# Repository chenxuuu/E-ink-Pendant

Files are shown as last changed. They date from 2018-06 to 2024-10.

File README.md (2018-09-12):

# E-ink Pendant

## 项目介绍
基于电子墨水屏与gprs的，科创纪念钥匙链挂饰，服务器为php驱动

## 项目文件结构
- 硬件设计
  - 硬件资料
  - 硬件工程文件
- 嵌入式软件
  - Air202工程脚本
  - Air202所用固件
- 服务器部分
  - 服务器整体框架
  - 公开的二次开发api以及demo sdk

## 需要实现的功能
- 驱动电子墨水屏幕，SPI控制，分辨率200*200
- 锂电池供电，可实时显示电压（剩余电量）
- 可充电
- 定时刷新电子墨水屏界面
- 界面显示内容可在网站端设置
- 所有设置可在网站端修改
- 提供屏幕显示内容模板
- 提供自定义显示内容模板设置（开放api）
- 提供外部链接的api接口
- 网站的账号注册以及绑定设备流程

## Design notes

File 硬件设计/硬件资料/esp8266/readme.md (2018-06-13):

# 淘宝链接

https://item.taobao.com/item.htm?id=538926731077

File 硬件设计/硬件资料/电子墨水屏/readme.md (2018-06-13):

# 淘宝链接

https://item.taobao.com/item.htm?id=45437569090

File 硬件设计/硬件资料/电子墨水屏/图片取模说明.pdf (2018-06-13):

# GDEH0154D27 图片制作及取模说明

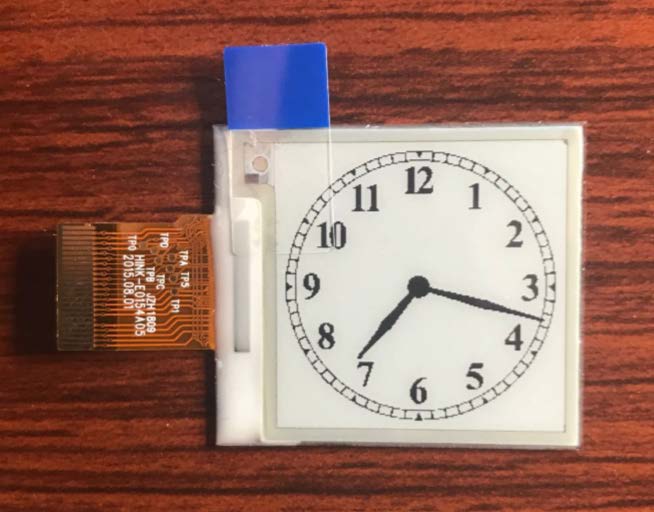
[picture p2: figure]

图一

### 以实现上图效果为例，对图片制作及取模加以简要说明。

一、 | 图片制作
| 因为该款屏不支持灰度，所以在制作图片的时候，需要做成 200*200 分辨率的

纯黑白图片，保存成.bmp 位图文件。

二、 取模

取模可以采用 image2lcd 软件，取模参数设置见图二：

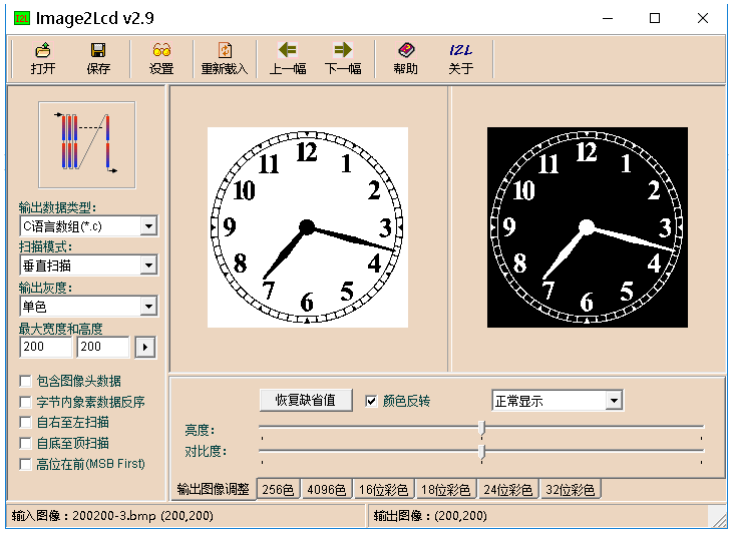
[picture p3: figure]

图二

1、 打开 image2lcd，调入需要取模的图片；

2、 输出数据类型：选择“C 语言数组（*.c）”；

3、 扫描方式：选择“垂直扫描”；

4、 输出灰度：选择“单色”；

5、 最大宽度和高度：选择“200”、“200”，选择后需要点击后面的箭头确认；

6、 左下方的 5 个选项都不要打钩；

7、 正显（白底黑字），则“颜色反转”打钩；负显（黑底白字）则不需要打钩。

8、 点击“保存”，把转换后的数组存到扩展名为“.C”文件；

9、 最后把文件“.C”中的数组替换掉程序中对应的数组。

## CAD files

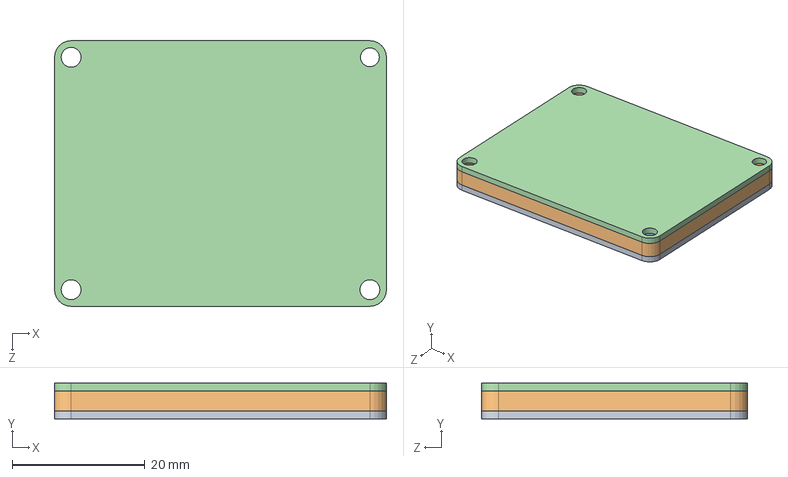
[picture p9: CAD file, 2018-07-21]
硬件设计/外壳图纸/装配体1.SLDASM
50.0 x 5.40 x 40.0 mm
下板
中板
电池
上板

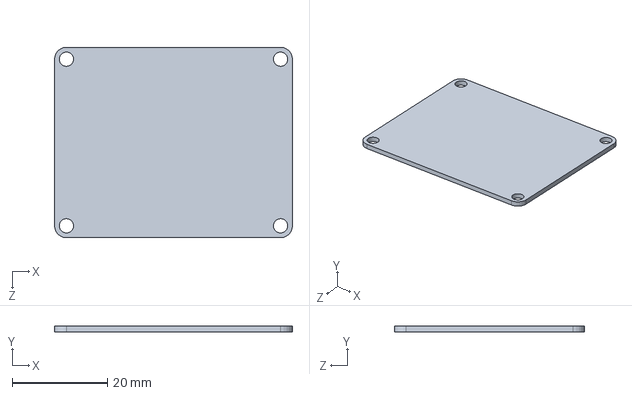
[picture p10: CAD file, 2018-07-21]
硬件设计/外壳图纸/下板.SLDPRT
50.0 x 1.20 x 40.0 mm

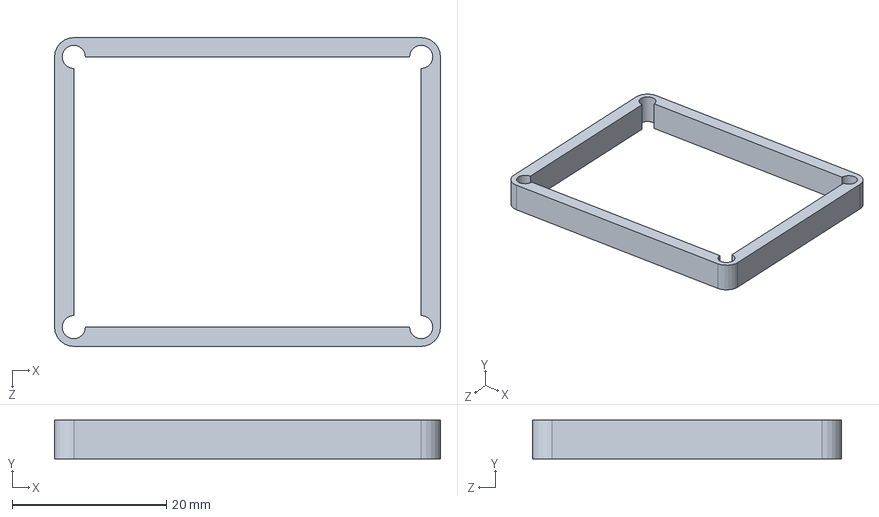
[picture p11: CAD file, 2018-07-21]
硬件设计/外壳图纸/中板.SLDPRT
50.0 x 5.00 x 40.0 mm

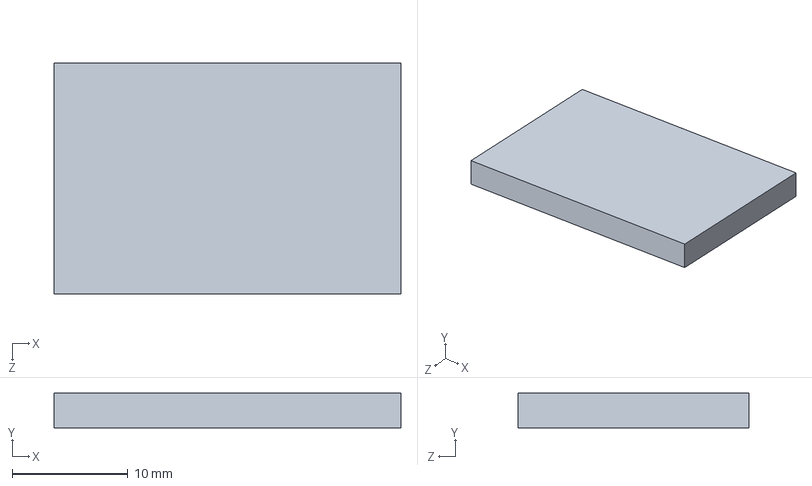
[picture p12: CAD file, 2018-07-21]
硬件设计/外壳图纸/电池.SLDPRT
30.0 x 3.00 x 20.0 mm

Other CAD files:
硬件设计/外壳图纸/上板.SLDPRT

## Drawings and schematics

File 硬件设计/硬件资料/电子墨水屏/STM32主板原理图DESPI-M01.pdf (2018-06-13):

## Current test1

## ASM1117-3.3

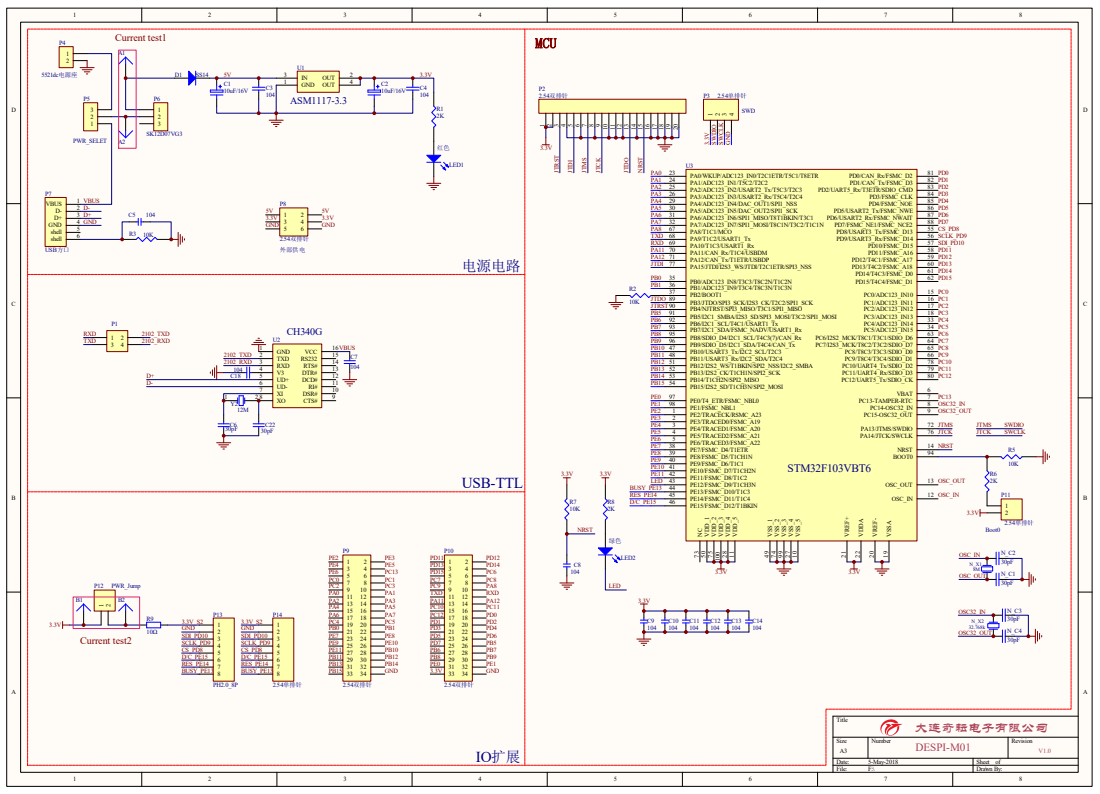
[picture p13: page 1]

SWD 3.3V SWDIO SWCLK GND

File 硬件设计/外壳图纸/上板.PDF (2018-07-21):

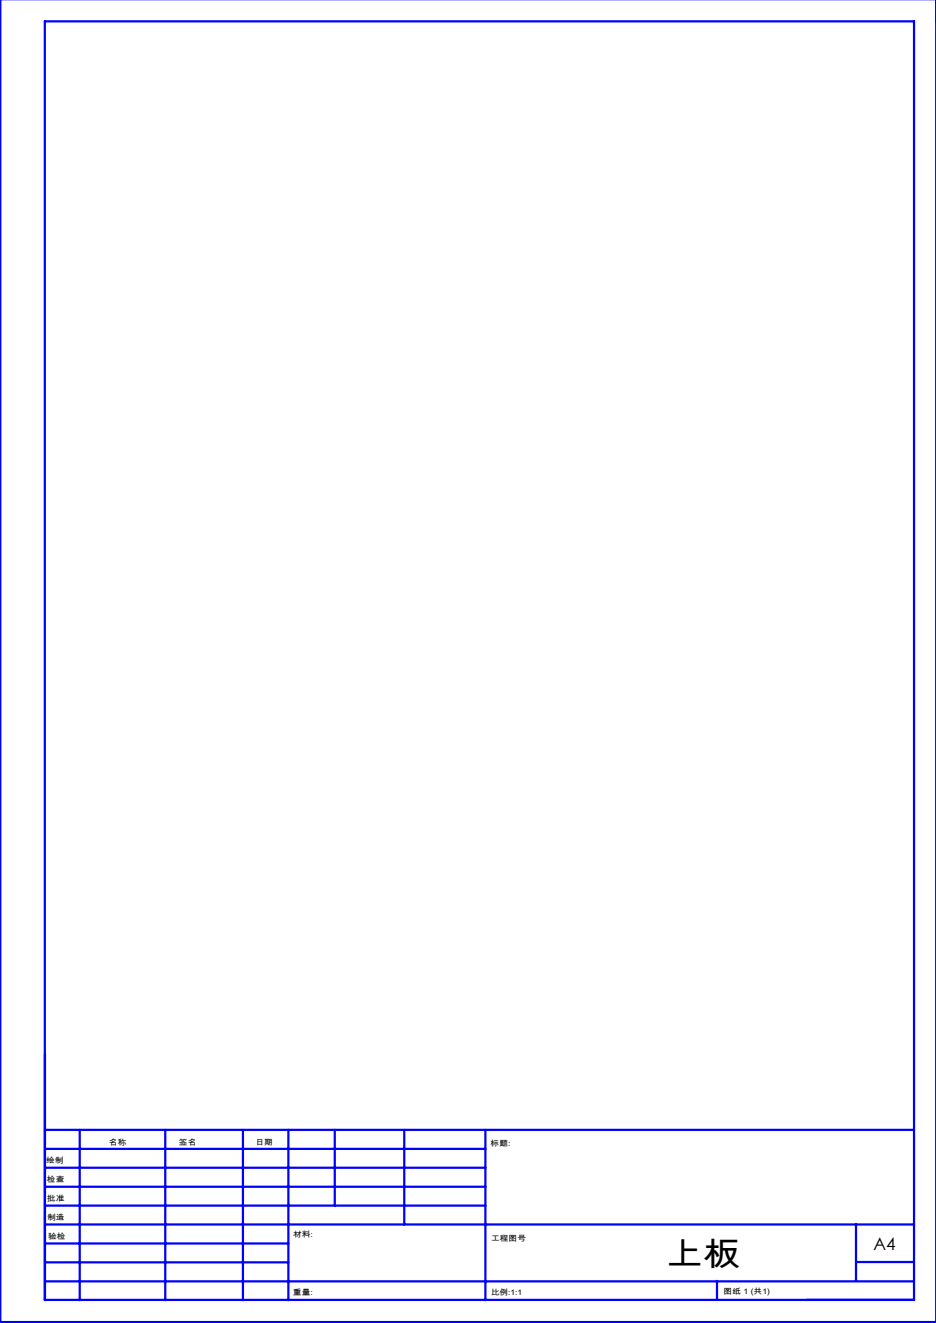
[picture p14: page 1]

绘制
检查
批准
制造
验检 | | | | 材料: | 上板 重量: 工程图号 | A4

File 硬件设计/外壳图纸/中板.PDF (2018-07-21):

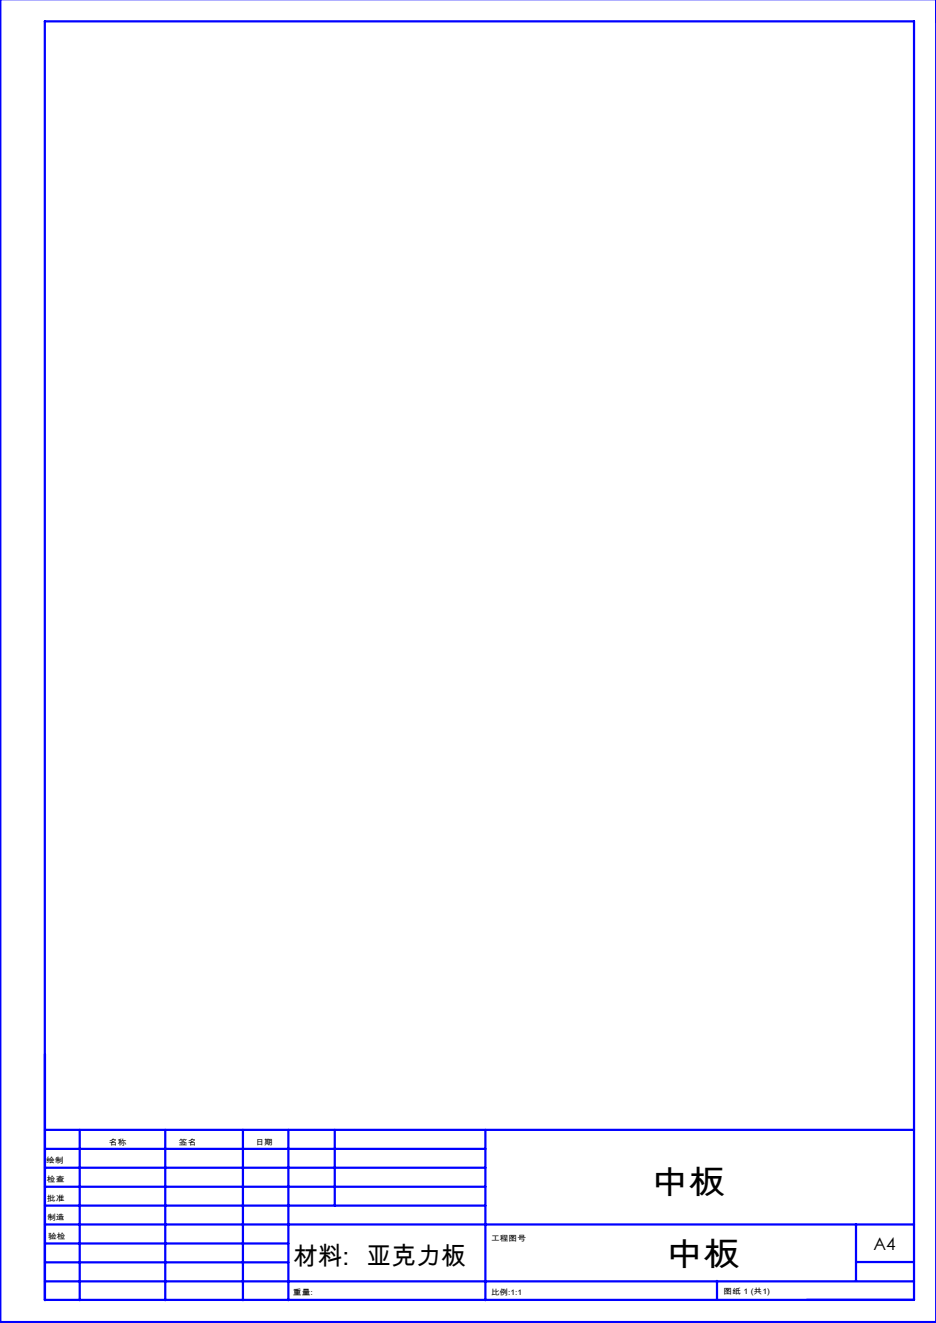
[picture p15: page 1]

绘制
检查
批准
制造
验检 | | | | 亚克力板 材料: | 中板 重量: 工程图号 | A4

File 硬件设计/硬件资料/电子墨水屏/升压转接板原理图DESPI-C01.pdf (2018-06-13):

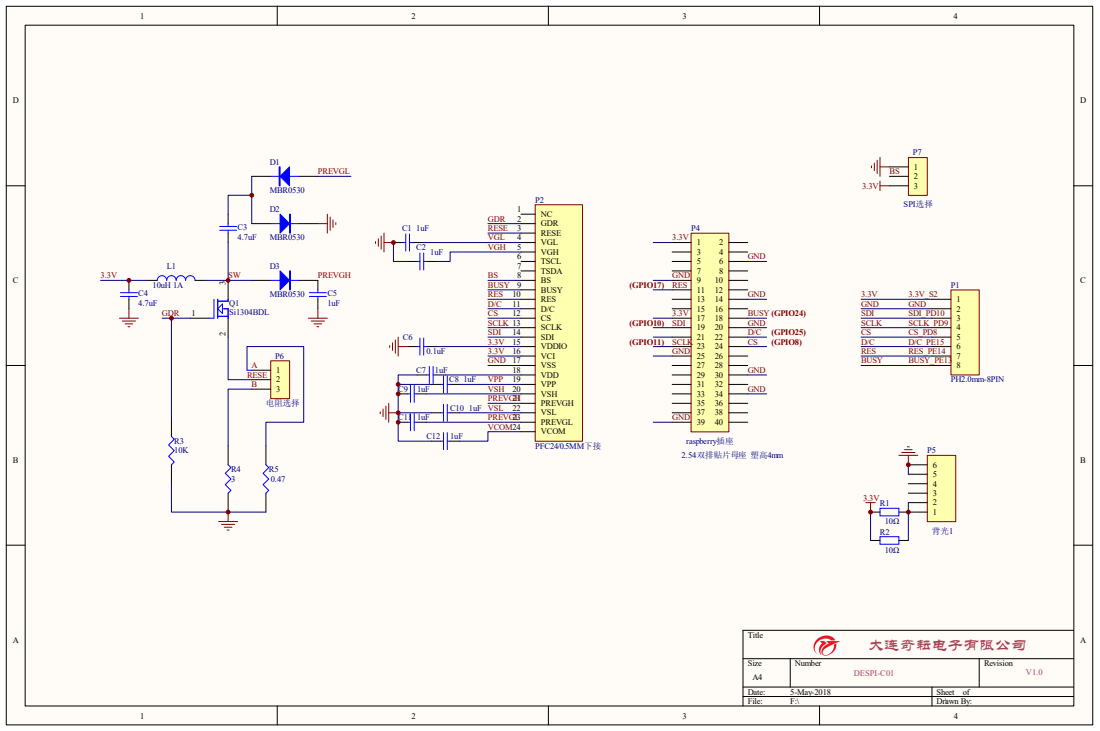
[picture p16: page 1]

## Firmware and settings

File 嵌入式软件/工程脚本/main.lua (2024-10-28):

--必须在这个位置定义PROJECT和VERSION变量
--PROJECT：ascii string类型，可以随便定义，只要不使用,就行
--VERSION：ascii string类型，如果使用Luat物联云平台固件升级的功能，必须按照"X.X.X"定义，X表示1位数字；否则可随便定义
PROJECT = "E-INK"
VERSION = "1.0.4"

--加载日志功能模块，并且设置日志输出等级
--如果关闭调用log模块接口输出的日志，等级设置为log.LOG_SILENT即可
require "log"
LOG_LEVEL = log.LOG_SILENT
LOG_LEVEL = log.LOGLEVEL_TRACE

require "sys"
--如果是关机闹钟开机，则需要软件主动重启一次，才能启动GSM协议栈
if rtos.poweron_reason()==rtos.POWERON_ALARM then
    sys.restart("ALARM_ON")
end

require "net"
--每1分钟查询一次GSM信号强度
--每1分钟查询一次基站信息
net.startQueryAll(60000, 60000)

--加载硬件看门狗功能模块
--根据自己的硬件配置决定：1、是否加载此功能模块；2、配置Luat模块复位单片机引脚和互相喂狗引脚
--合宙官方出售的Air201开发板上有硬件看门狗，所以使用官方Air201开发板时，必须加载此功能模块
-- require "wdt"
-- wdt.setup(pio.P0_30, pio.P0_31)


--加载网络指示灯功能模块
--根据自己的项目需求和硬件配置决定：1、是否加载此功能模块；2、配置指示灯引脚
--合宙官方出售的Air800和Air801开发板上的指示灯引脚为pio.P0_28，其他开发板上的指示灯引脚为pio.P1_1
require "netLed"
netLed.setup(true,pio.P1_1)
--网络指示灯功能模块中，默认配置了各种工作状态下指示灯的闪烁规律，参考netLed.lua中ledBlinkTime配置的默认值
--如果默认值满足不了需求，此处调用netLed.updateBlinkTime去配置闪烁时长

--加载错误日志管理功能模块【强烈建议打开此功能】
--如下2行代码，只是简单的演示如何使用errDump功能，详情参考errDump的api
require "errDump"
errDump.request("udp://ota.airm2m.com:9072")

--加载远程升级功能模块【强烈建议打开此功能】
--如下3行代码，只是简单的演示如何使用update功能，详情参考update的api以及demo/update
PRODUCT_KEY = "a79KxY1I3CJ5m6KymLWLfYZGn0lcqNZz"
-- require "update"
-- update.request()

require "epd1in54"
require "picdata"
require "key"

--启动系统框架
sys.init(0, 0)
sys.run()

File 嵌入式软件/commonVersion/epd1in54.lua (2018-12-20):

module(..., package.seeall)
require"misc"
require"utils"

local function getBusyFnc(msg)
    log.info("Gpio.getBusyFnc",msg)
    if msg==cpu.INT_GPIO_POSEDGE then--上升沿中断
        --不动作
    else--下降沿中断
        sys.publish("BUSY_DOWN")
    end
end

local getBusy         = pins.setup(pio.P0_6,getBusyFnc)
local setRST          = pins.setup(pio.P0_5,1)
local setDC           = pins.setup(pio.P0_4,1)

lut_full_update = {
    0x66,
    0x66,
    0x44,
    0x66,
    0xAA,
    0x11,
    0x80,
    0x08,
    0x11,
    0x18,
    0x81,
    0x18,
    0x11,
    0x88,
    0x11,
    0x88,
    0x11,
    0x88,
    0x00,
    0x00,
    0xFF,
    0xFF,
    0xFF,
    0xFF,
    0x5F,
    0xAF,
    0xFF,
    0xFF,
    0x2F,
    0x00
}
lut_partial_update = {
    0x10
    ,0x18
    ,0x18
    ,0x28
    ,0x18
    ,0x18
    ,0x18
    ,0x18
    ,0x08
    ,0x00
    ,0x00
    ,0x00
    ,0x00
    ,0x00
    ,0x00
    ,0x00
    ,0x00
    ,0x00
    ,0x00
    ,0x00
    ,0x13
    ,0x11
    ,0x22
    ,0x63
    ,0x11
    ,0x00
    ,0x00
    ,0x00
    ,0x00
    ,0x00
}

-- Display resolution
local EPD_WIDTH       = 200
local EPD_HEIGHT      = 200

-- EPD1IN54 commands
local DRIVER_OUTPUT_CONTROL                       = 0x01
local BOOSTER_SOFT_START_CONTROL                  = 0x0C
local GATE_SCAN_START_POSITION                    = 0x0F
local DEEP_SLEEP_MODE                             = 0x10
local DATA_ENTRY_MODE_SETTING                     = 0x11
local SW_RESET                                    = 0x12
local TEMPERATURE_SENSOR_CONTROL                  = 0x1A
local MASTER_ACTIVATION                           = 0x20
local DISPLAY_UPDATE_CONTROL_1                    = 0x21
local DISPLAY_UPDATE_CONTROL_2                    = 0x22
local WRITE_RAM                                   = 0x24
local WRITE_VCOM_REGISTER                         = 0x2C
local WRITE_LUT_REGISTER                          = 0x32
local SET_DUMMY_LINE_PERIOD                       = 0x3A
local SET_GATE_TIME                               = 0x3B
local BORDER_WAVEFORM_CONTROL                     = 0x3C
local SET_RAM_X_ADDRESS_START_END_POSITION        = 0x44
local SET_RAM_Y_ADDRESS_START_END_POSITION        = 0x45
local SET_RAM_X_ADDRESS_COUNTER                   = 0x4E
local SET_RAM_Y_ADDRESS_COUNTER                   = 0x4F
local TERMINATE_FRAME_READ_WRITE                  = 0xFF

--打开SPI引脚的供电
pmd.ldoset(5,pmd.LDO_VMMC)
--[[
功能：配置SPI

参数：
id：SPI的ID，spi.SPI_1表示SPI1，Air201、Air202、Air800只有SPI1，固定传spi.SPI_1即可
cpha：spi_clk idle的状态，仅支持0和1，0表示低电平，1表示高电平
cpol：第几个clk的跳变沿传输数据，仅支持0和1，0表示第1个，1表示第2个
dataBits：数据位，仅支持8
clock：spi时钟频率，支持110K到13M（即110000到13000000）之间的整数（包含110000和13000000）
duplex：是否全双工，仅支持0和1，0表示半双工（仅支持输出），1表示全双工。此参数可选，默认半双工

返回值：number类型，1表示成功，0表示失败
]]
log.info("spi.setup",spi.setup(spi.SPI_1,0,0,8,13000000,0,0))

local function wait()
    if getBusy() == 1 then  -- 0: idle, 1: busy
        sys.waitUntil("BUSY_DOWN",5000)
    end
end

setDC(1)
local function sendCommand(data)
    --log.info("epd1in45.sendCommand",data)
    setDC(0)
    spi.send(spi.SPI_1,string.char(data))
end

local function sendData(data)
    --log.info("epd1in45.sendData",data)
    setDC(1)
    spi.send(spi.SPI_1,string.char(data))
end

local function sendDataString(data)
    --log.info("epd1in45.sendData",data)
    setDC(1)
    spi.send(spi.SPI_1,data)
end

local function sendDataTrans(data)
    setDC(1)
    local temp
    for i=1,200 do
        for j=25,1,-1 do
            temp = (j-1)*200+i
            --log.info("epd1in45.temp",temp)
            spi.send(spi.SPI_1,data:sub(temp,temp))
        end
    end
end

local function reset()
    log.info("epd1in45.reset","")
    setRST(0)
    sys.wait(200)
    setRST(1)
    sys.wait(200)
end

function deepSleep()
    log.info("epd1in45.deepSleep","")
    sendCommand(0x10)
    wait()
end

local function set_lut(lut)
    log.info("epd1in45.set_lut","")
    sendCommand(WRITE_LUT_REGISTER)
    for i= 1, #lut do
        sendData(lut[i])
    end
end

function init(lut)
    log.info("epd1in45.init","")
    if lut == nil then
        lut = lut_full_update
    end
    reset()
    sendCommand(DRIVER_OUTPUT_CONTROL)
    sendData(bit.band(EPD_HEIGHT-1,0xff))
    sendData(bit.band(bit.rshift(EPD_HEIGHT-1,8),0xff))
    sendData(0x00)
    sendCommand(BOOSTER_SOFT_START_CONTROL)
    sendData(0xD7)
    sendData(0xD6)
    sendData(0x9D)
    sendCommand(WRITE_VCOM_REGISTER)
    sendData(0xA8)
    sendCommand(SET_DUMMY_LINE_PERIOD)
    sendData(0x1A)
    sendCommand(SET_GATE_TIME)
    sendData(0x08)
    sendCommand(DATA_ENTRY_MODE_SETTING)
    sendData(0x03)
    set_lut(lut)
    log.info("epd1in45.init","done")
end

local function set_memory_area(x_start, y_start, x_end, y_end)
    log.info("epd1in45.set_memory_area",x_start, y_start, x_end, y_end)
    sendCommand(SET_RAM_X_ADDRESS_START_END_POSITION)
    -- x point must be the multiple of 8 or the last 3 bits will be ignored
    sendData(bit.band(bit.rshift(x_start,3),0xff))
    sendData(bit.band(bit.rshift(x_end,3),0xff))
    sendCommand(SET_RAM_Y_ADDRESS_START_END_POSITION)
    sendData(bit.band(y_start,0xff))
    sendData(bit.band(bit.rshift(y_start,8),0xff))
    sendData(bit.band(y_end,0xff))
    sendData(bit.band(bit.rshift(y_end,8),0xff))
    log.info("epd1in45.set_memory_area","done")
end

local function set_memory_pointer(x,y)
    log.info("epd1in45.set_memory_pointer",x,y)
    sendCommand(SET_RAM_X_ADDRESS_COUNTER)
    -- x point must be the multiple of 8 or the last 3 bits will be ignored
    sendData(bit.band(bit.rshift(x,3),0xff))
    sendCommand(SET_RAM_Y_ADDRESS_COUNTER)
    sendData(bit.band(y,0xff))
    sendData(bit.band(bit.rshift(y,8),0xff))
    wait()
    log.info("epd1in45.set_memory_pointer","done")
end

function clear_frame_memory(color)
    log.info("epd1in45.clear_frame_memory",color)
    set_memory_area(0, 0, EPD_WIDTH - 1, EPD_HEIGHT - 1)
    set_memory_pointer(0, 0)
    sendCommand(WRITE_RAM)
    for i= 1, EPD_WIDTH / 8 * EPD_HEIGHT do
        sendData(color)
    end
    log.info("epd1in45.clear_frame_memory","done")
end

function display_frame()
    log.info("epd1in45.display_frame","start")
    sendCommand(DISPLAY_UPDATE_CONTROL_2)
    sendData(0xC7)
    sendCommand(MASTER_ACTIVATION)
    sendCommand(TERMINATE_FRAME_READ_WRITE)
    wait()
    log.info("epd1in45.display_frame","done")
end

--输入值：数组
function showPictureN(pic)
    wait()
    log.info("epd1in45.showPicture","")
    set_memory_area(0, 0, EPD_WIDTH - 1, EPD_HEIGHT - 1)
    set_memory_pointer(0, 0)
    sendCommand(WRITE_RAM)
    for i=1,#pic do
        sendData(pic[i])
    end
    display_frame()
end

--输入值：string
function showPicture(pic)
    wait()
    log.info("epd1in45.showPicture","")
    set_memory_area(0, 0, EPD_WIDTH - 1, EPD_HEIGHT - 1)
    set_memory_pointer(0, 0)
    sendCommand(WRITE_RAM)
    sendDataString(pic)
    display_frame()
end
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

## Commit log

2018-06-11 初始化所有文件
2018-06-11 添加esp8266的datasheet
2018-06-13 上传资料
    [ESP8266_TESTER.sch]
2018-06-14 上传空工程和gitignore模板
    [PCB_Project1.PrjPCB, Schlib2.SchLib, Sheet1.SchDoc]
2018-06-14 完善readme
2018-06-14 漏掉了一个文件夹。。
2018-06-15 Upload 器件选择.xlsx
    [器件选择.xlsx]
2018-06-15 Upload Sheet1.SchDoc
    [Sheet1.SchDoc]
2018-06-15 Upload 硬件工程.PrjPcb
    [硬件工程.PrjPcb]
2018-06-15 更新 .gitignore
2018-06-15 删除文件硬件设计/硬件工程/Schlib2.SchLib
    [Schlib2.SchLib]
2018-06-15 删除文件硬件设计/硬件工程/PCB_Project1.PrjPCB
    [PCB_Project1.PrjPCB]
2018-06-15 删除文件硬件设计/硬件工程/PcbLib1.PcbLib
2018-06-15 Upload TP4056.SchLib TP4056.PcbLib
    [TP4056.PcbLib, TP4056.SchLib]
2018-06-16 测试上传
    [Sheet1.SchDoc]
2018-06-16 删除文件硬件设计/硬件工程/TP4056.SchLib
    [TP4056.SchLib]
2018-06-16 删除文件硬件设计/硬件工程/TP4056.PcbLib
    [TP4056.PcbLib]
2018-06-16 板子基本成型，电路暂用 模拟spi 硬件spi接口还在研究。
    [Sheet1.SchDoc, 硬件工程.PrjPcb]
2018-06-16 板子基本成型，spi暂时使用模拟spi，硬件spi接口还在研究
    [PCB1.PcbDoc]
2018-06-17 上传固件
2018-06-17 电路图已改为硬件spi接法，附加电路图导成pdf格式了。
    [Sheet1.SchDoc, 硬件工程.PrjPcb]
2018-06-17 修改为硬件spi接口，上传没显示啊
    [硬件工程.PrjPcb]
2018-06-17 提交没反应，测试一下
2018-06-17 电路改为硬件spi接法，工程导出为pdf文件。
    [Sheet1.SchDoc]
2018-06-17 新建 外壳图纸/.keep
2018-06-17 重命名文件硬件设计/外壳图纸/.keep为硬件设计/外壳图纸/.gitignore
2018-06-18 修改丝印层
2018-06-18 更新一下
2018-06-18 外壳暂定
    [上板.SLDPRT, 下板.SLDPRT, 中板.SLDPRT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]
2018-06-19 新建 电池选择
2018-07-08 增加外部按键，修改屏幕与esp8266的连接
    [Sheet1.SchDoc, 硬件工程.PrjPcb]
2018-07-10 增加GPRS方案
    [PCB_Project1.PrjPCB, Sheet2.SchDoc]
2018-07-10 增加按键，更改屏幕连线
2018-07-21 脚本实现基本的屏幕显示功能
2018-07-21 嵌入式脚本功能完成
2018-07-21 程序去掉看门狗
2018-07-21 pcb等着布线
    [PCB1.PcbDoc, PCB_Project1.PrjPCB, Sheet2.SchDoc]
2018-07-21 某人做的登陆注册页，估计用不着
2018-07-21 手动布线
    [PCB1.PcbDoc, PCB_Project1.PrjPCB, Sheet2.SchDoc]
2018-07-21 修改电容位置
    [PCB1.PcbDoc]
2018-07-21 加了点字
2018-07-21 修该边框图层
2018-07-21 修该线间距为7mil 检测规则检测时改为6mil usb封装问题
2018-07-22 关机前延时3秒，以免屏幕来不及刷新完
2018-07-22 实现了基本功能的php api
2018-07-22 天气显示demo完成
2018-07-22 文件改个名
2018-07-22 温度位置微调
2018-07-22 加上电量显示
2018-07-22 设置页前端设计完成
2018-07-22 主显示界面逻辑完成
2018-07-22 完成后台设置
2018-07-22 完成设备获取信息api
2018-07-22 修正没法跳转的bug
2018-07-22 改掉不兼容的波浪线
2018-07-23 关机前先进行休眠
2018-07-23 更改api处的提示
2018-08-08 修正休眠函数无法调用的问题
2018-09-04 重构嵌入式代码，更改服务的下发数据的格式
2018-09-05 增加长按三秒关机逻辑，更正解析逻辑，更正服务端天气api生成重启时间结果错误的逻辑，
2018-09-05 更正获取天气参数没有key的问题
2018-09-05 更新硬件工程
    [PCB2.PcbDoc, PCB_Project.PrjPcb, PCB_Project1.PrjPCB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]
2018-09-05 api中的时间日期显示内容微调
2018-09-05 远程升级、启动界面调整
2018-09-05 升级包获取函数加上imei参数
2018-09-05 增加一言接口
2018-09-06 存储获取数据成功的数据，当某次获取失败后，自动再次使用上次获取到的数据
2018-09-06 php端微调电量计算标准，嵌入式端多次测电压取最大值
2018-09-07 嵌入式程序加上两分钟超时自动关机，php端21-6时禁止刷新
2018-09-07 更新硬件工程，软件定时器关机前再次使用上次开机信息
    [PCB2.PcbDoc, PCB_Project.PrjPcb, Sheet1.SchDoc]
2018-09-08 增加数据log功能，记录每次获取的数据
2018-09-08 显示历史刷新数据
2018-09-08 查快全部log，log信息完善，api中加上便捷调试参数
2018-09-08 更正电压显示不正确的问题
2018-09-08 增加升级工具代码
2018-09-08 去除升级返回数据中的错误，并禁用错误显示
2018-09-09 更正升级获取失败后的判断，更正超时后的显示
2018-09-10 电量过低时禁止自动开机
2018-09-10 更正21-6时刷新延时的计算，去除模块log显示以免被逆向
2018-09-10 更换开机界面
2018-09-11 用重复算法编码返回结果，节省流量，效果待测试
2018-09-12 服务端整合升级功能到同一个文件，简化请求；实现芯片中编码图片显示算法
2018-09-12 获取图片数据后，停止关机倒计时
2018-09-12 更改readme
2018-09-12 更正空api的判断
2018-09-13 无法定位时，使用上次定位结果
2018-09-16 新增图片数据生成工具，更正图片输出bug
2018-09-16 更新网页介绍，更正图片数据生成工具显示少2行2列像素的问题，嵌入式代码解析图片时每1500延时一秒以免重启
2018-10-24 加上提示语
2018-12-17 通用版框架
2018-12-18 增加图片保存为二进制文件的功能
2018-12-19 优化busy检测等待，增加充电检测引脚
2018-12-20 支持底层库，图片处理工具支持生成1位bmp图片
2019-04-12 处理插入充电器循环开机问题
2019-05-07 插入充电器不延时重启，防止循环重启
2024-10-28 update: 没上传的更新内容
